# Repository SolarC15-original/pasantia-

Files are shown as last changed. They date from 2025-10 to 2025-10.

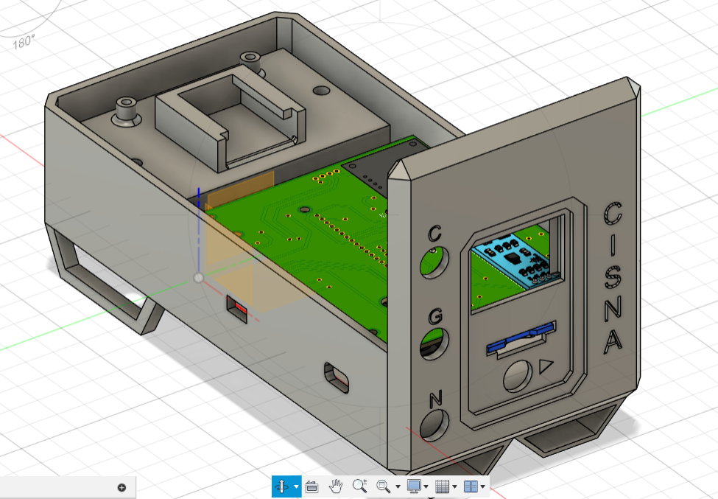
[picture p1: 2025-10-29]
modelo 3D caja ulima version/DiseñoFInal fotos/parte interna.png

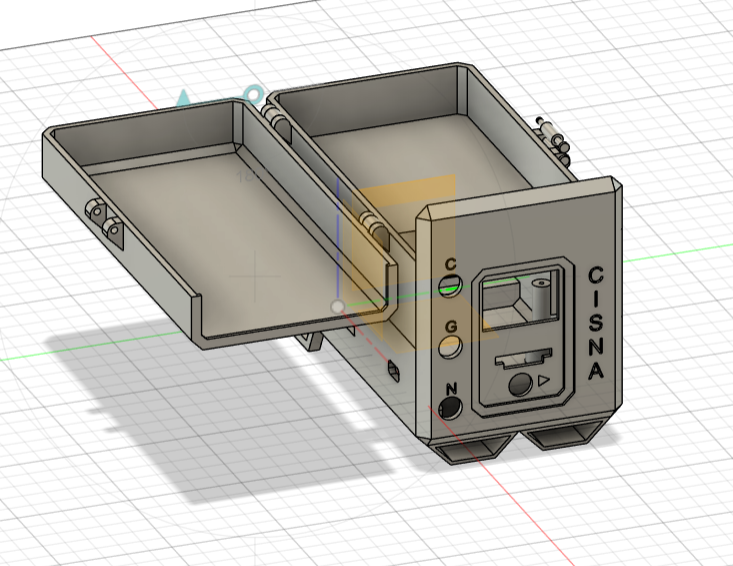
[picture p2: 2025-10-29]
modelo 3D caja ulima version/DiseñoFInal fotos/CajaFinal.png

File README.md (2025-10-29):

## 🎯 Propósito del repositorio

El propósito de este repositorio es **documentar y compartir todo el trabajo técnico realizado** durante el desarrollo del sensor NPK.  
Aquí se incluyen los archivos, códigos y recursos generados para facilitar la **continuidad del proyecto** y servir como referencia para futuros desarrollos o mejoras.

---

## 🧩 Contenido del repositorio

- `/3D_Model/` → Archivos del diseño 3D de la carcasa del sensor (formatos STL y editables).  
- `/Code/` → Código fuente del microcontrolador con las correcciones implementadas.  
- `/Docs/` → Documentación técnica, diagramas y reportes del proceso.  
- `/Tests/` → Registros de pruebas y observaciones de funcionamiento.  

---

## ⚙️ Funcionalidades principales

- Lectura de nutrientes NPK mediante sensor integrado.  
- Registro automático de la **fecha y hora** de toma de muestra.  
- Almacenamiento de datos en tarjeta SD.  
- Detección y notificación de **errores en la SD** o en los sensores.  
- Diseño modular y resistente para uso en campo.  

---

## 🧠 Tecnologías utilizadas

- **Arduino / C++** para programación del microcontrolador.  
- **Fusion 360 / FreeCAD** para diseño 3D.  
- **Sensores NPK y módulo SD** para adquisición y almacenamiento de datos.  
- **Impresoras 3D** para la fabricación de prototipos.  

---

## 📊 Resultados

- Carcasa 3D funcional, con mejoras en las dimensiones luego del primer prototipo.  
- Dispositivo completamente ensamblado y probado con muestras reales de suelo.  
- Código actualizado con manejo de fechas y detección de errores en la tarjeta SD.  

---

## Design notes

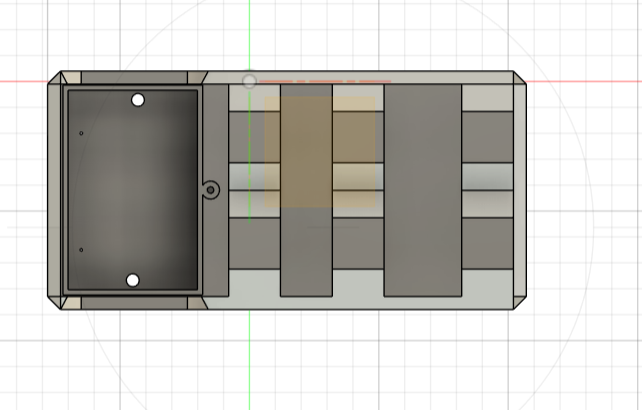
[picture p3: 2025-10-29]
modelo 3D caja ulima version/DiseñoFInal fotos/Parte inferior.png

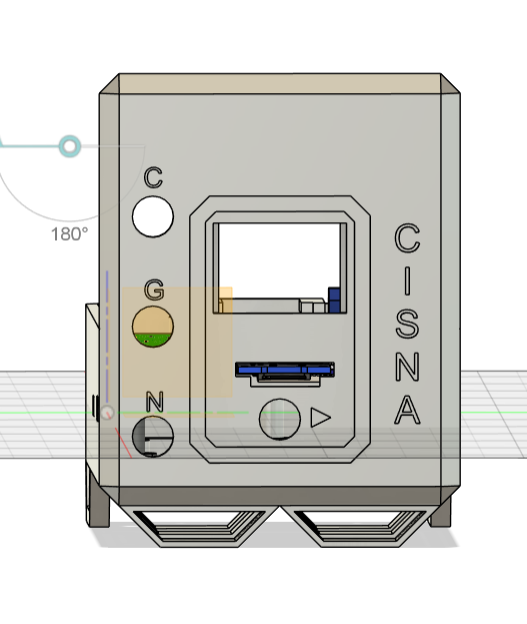
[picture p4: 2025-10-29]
modelo 3D caja ulima version/DiseñoFInal fotos/Tapa frontal.png

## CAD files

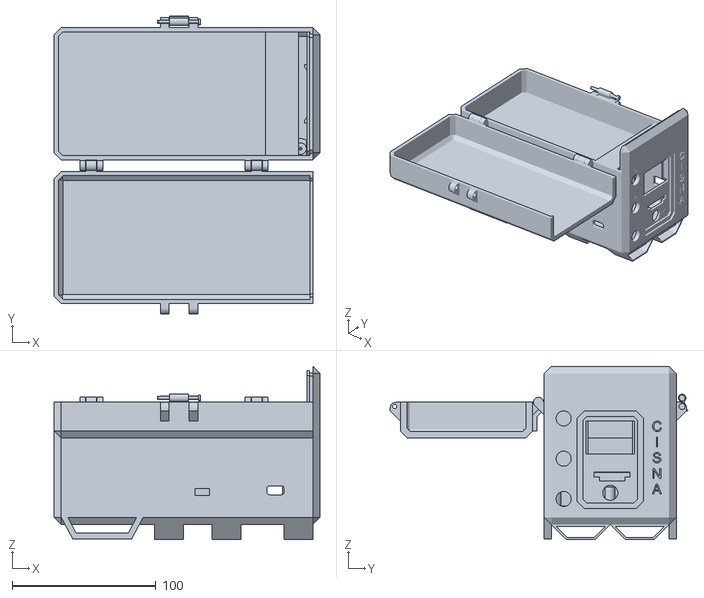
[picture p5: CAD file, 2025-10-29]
modelo 3D caja ulima version/cajanueva v11.stl
185.0 x 207.0 x 120.6

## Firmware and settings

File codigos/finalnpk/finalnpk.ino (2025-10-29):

#include <Wire.h>             // Librería para la comunicación I2C, usada por el OLED
#include <Adafruit_GFX.h>      // Biblioteca gráfica base para las pantallas Adafruit
#include <Adafruit_SH110X.h>   // Biblioteca específica para pantallas SH1106 (OLED)
#include <TinyGPS++.h>         // Biblioteca para interpretar datos del GPS
#include <SD.h>                // Biblioteca para manejo de tarjetas SD
#include <SPI.h>               // Biblioteca para la comunicación SPI (necesaria para la SD)

// ================== Configuración OLED ==================
#define SCREEN_WIDTH 128       // Ancho en píxeles de la pantalla OLED
#define SCREEN_HEIGHT 64       // Altura en píxeles de la pantalla OLED
#define OLED_RESET -1          // Pin de reset (no se utiliza un pin físico en este caso)
Adafruit_SH1106G display(SCREEN_WIDTH, SCREEN_HEIGHT, &Wire, OLED_RESET);

#define GPS_RX 4               // Pin para recibir datos del GPS
#define GPS_TX 2               // Pin para enviar datos al GPS (aunque realmente solo se recibe)
HardwareSerial GPSSerial(1);   // Se crea un puerto serial adicional para el GPS
TinyGPSPlus gps;               // Objeto para procesar la información del GPS

#define RO 33                  // Pin RX para el sensor de suelo vía RS485
#define DI 32                  // Pin TX para el sensor de suelo
#define RE 26                  // Pin para activar la recepción
#define DE 25                  // Pin para activar la transmisión

#define BUTTON_SAVE 14         // Pin asignado para el botón de guardar datos
#define BUTTON_NEW 27          // Pin asignado para el botón de crear un nuevo archivo
#define BUTTON_REFRESH 12      // Pin asignado para el botón de refrescar pantalla
#define SD_CS 5                // Pin Chip Select para la tarjeta SD
#define DEBOUNCE 200           // Tiempo de "debounce" para evitar múltiples activaciones

volatile uint8_t screenState = 0; // Estado de la pantalla: 0 = Sistema, 1 = Suelo
volatile bool flags[3] = {false, false, false}; // Flags para eventos: [refresh, save, newFile]
unsigned long lastInterrupt = 0;  // Controla el tiempo entre interrupciones
String currentFile = "";          // Guarda el nombre del archivo actual en la SD

struct SensorData {
  // Datos del GPS
  double lat = 0.0;
  double lng = 0.0;
  uint8_t hour = 0;
  uint8_t minute = 0;
  uint8_t second = 0;
  bool gpsValid = false;
  
  // Datos del sensor de suelo
  float temp = -1.0;
  float humidity = -1.0;
  unsigned int ec = 0;
  float ph = -1.0;
  unsigned int n = 0;
  unsigned int p = 0;
  unsigned int k = 0;
  unsigned int sal = 0;
  bool sensorValid = false;
};
class SoilSensor {
private:
  // Comando para solicitar datos del sensor (según protocolo RS485)
  const byte cmd[8] = {0x01, 0x03, 0x00, 0x00, 0x00, 0x08, 0x44, 0x0C};
  byte response[21]; // Buffer donde se almacena la respuesta del sensor
  
  // Función para combinar dos bytes y formar un entero de 16 bits
  uint16_t combinarBytes(uint8_t high, uint8_t low) {
    return (high << 8) | low;
  }

public:
  // Inicializa el sensor configurando el puerto serie y los pines de control
  void iniciar() {
    Serial2.begin(9600, SERIAL_8N1, RO, DI);
    pinMode(RE, OUTPUT);
    pinMode(DE, OUTPUT);
    digitalWrite(RE, LOW);
    digitalWrite(DE, LOW);
  }

  // Envía el comando al sensor y procesa la respuesta para actualizar los datos
  bool leer(SensorData &data) {
    // Activa la transmisión para enviar el comando
    digitalWrite(DE, HIGH);
    digitalWrite(RE, HIGH);
    delay(10);
    Serial2.write(cmd, 8);
    Serial2.flush();
    // Desactiva la transmisión para empezar a leer la respuesta
    digitalWrite(DE, LOW);
    digitalWrite(RE, LOW);

    uint8_t idx = 0;
    unsigned long inicio = millis();
    // Espera hasta 1 segundo o hasta recibir los 21 bytes esperados
    while((millis() - inicio < 1000) && (idx < 21)) {
      if(Serial2.available()) {
        response[idx++] = Serial2.read();
      }
    }
    
    // Verifica la integridad de la respuesta y asigna los valores a 'data'
    if(idx == 21 && response[0] == 0x01 && response[1] == 0x03) {
      data.temp = combinarBytes(response[3], response[4]) / 10.0;
      data.humidity = combinarBytes(response[5], response[6]) / 10.0;
      data.ec = combinarBytes(response[7], response[8]);
      data.ph = combinarBytes(response[9], response[10]) / 100.0;
      data.n = combinarBytes(response[11], response[12]);
      data.p = combinarBytes(response[13], response[14]);
      data.k = combinarBytes(response[15], response[16]);
      data.sal = combinarBytes(response[17], response[18]);
      data.sensorValid = true; // Los datos recibidos son válidos
      return true;
    }
    data.sensorValid = false; // Si la respuesta falla, se marca el sensor como inválido
    return false;
  }
};

SoilSensor sensorSuelo;  // Instancia para manejar el sensor de suelo
SensorData datos;        // Variable global para almacenar los datos recopilados


void IRAM_ATTR handleRefresh() {
  if(millis() - lastInterrupt > DEBOUNCE) {
    flags[0] = true;
    lastInterrupt = millis();
  }
}

void IRAM_ATTR handleSave() {
  if(millis() - lastInterrupt > DEBOUNCE) {
    flags[1] = true;
    lastInterrupt = millis();
  }
}

void IRAM_ATTR handleNewFile() {
  if(millis() - lastInterrupt > DEBOUNCE) {
    flags[2] = true;
    lastInterrupt = millis();
  }
}

// ================== Función setup() ==================
void setup() {
  digitalWrite(22, LOW);  // Inicia el reinicio del sistema
  delay(1200); 
  Serial.begin(115200);   // Inicia la comunicación serial para debug

  // Inicializa la pantalla OLED y muestra la pantalla de inicio
  display.begin(0x3C, true);
  display.setTextColor(SH110X_WHITE);
  mostrarSplash();
  
  // Inicializa el GPS y el sensor de suelo
  GPSSerial.begin(9600, SERIAL_8N1, GPS_RX, GPS_TX);
  sensorSuelo.iniciar();
  
  // Configura los botones con resistencia interna pull-up
  pinMode(BUTTON_REFRESH, INPUT_PULLUP);
  pinMode(BUTTON_SAVE, INPUT_PULLUP);
  pinMode(BUTTON_NEW, INPUT_PULLUP);
  // Asocia cada botón a su función de interrupción
  attachInterrupt(BUTTON_REFRESH, handleRefresh, FALLING);
  attachInterrupt(BUTTON_SAVE, handleSave, FALLING);
  attachInterrupt(BUTTON_NEW, handleNewFile, FALLING);
  
  // Inicializa la tarjeta SD y crea un archivo nuevo para almacenar datos
  if(!SD.begin(SD_CS)) {
    mostrarError("Error en SD!");
    while(true);
  }
  crearNuevoArchivo();
}

void loop() {
  actualizarGPS();         // Procesa los datos entrantes del GPS
  actualizarSensorSuelo(); // Lee los datos del sensor de suelo
  manejarEventos();        // Maneja eventos generados por los botones
  actualizarPantalla();    // Refresca la pantalla OLED
  delay(100);
}


// Lee datos del puerto serial del GPS y actualiza la estructura 'datos'
void actualizarGPS() {
  while(GPSSerial.available()) {
    if(gps.encode(GPSSerial.read())) {
      // Verifica que tanto la ubicación como la hora sean válidas
      datos.gpsValid = gps.location.isValid() && gps.time.isValid();
      if(datos.gpsValid) {
        datos.lat = gps.location.lat();
        datos.lng = gps.location.lng();
        datos.hour = gps.time.hour()-5; // Ajuste de zona horaria a Colombia
        datos.minute = gps.time.minute();
        datos.second = gps.time.second();
      }
    }
  }
}

// Realiza una lectura del sensor cada 2 segundos
void actualizarSensorSuelo() {
  static unsigned long ultimaLectura = 0;
  if(millis() - ultimaLectura > 2000) {
    sensorSuelo.leer(datos);
    ultimaLectura = millis();
  }
}

//  Función para Manejar Eventos  
void manejarEventos() {
  if(flags[0]) { // Si se presionó el botón de refrescar
    screenState = (screenState + 1) % 2;
    flags[0] = false;
  }
  
  if(flags[1]) { // Si se presionó el botón de guardar datos
    guardarEnSD();
    flags[1] = false;
    mostrarMensajeTemporal("Dato Guardado");
  }
  
  if(flags[2]) { // Si se presionó el botón para nuevo archivo
    crearNuevoArchivo();
    flags[2] = false;
    mostrarMensajeTemporal("Nuevo Archivo");
  }
}

// Función para Crear un Nuevo Archivo en la SD 
void crearNuevoArchivo() {
  uint8_t numArchivo = 1;
  do {
    currentFile = "/DAT" + String(numArchivo < 10 ? "0" : "") + String(numArchivo) + ".CSV";
    numArchivo++;
  } while(SD.exists(currentFile));
  
  // Abre el archivo y designa los nombres de cada columna
  File archivo = SD.open(currentFile, FILE_WRITE);
  if(archivo) {
    archivo.println("Latitud,Longitud,Hora,Min,Seg,Temp,Humedad,CE,pH,N,P,K,Sal");
    archivo.close();
  }
}

// Función para Guardar Datos en la SD 
void guardarEnSD() {
  File archivo = SD.open(currentFile, FILE_APPEND);
  if(archivo) {
    archivo.printf("%.6f,%.6f,%02d,%02d,%02d,%.1f,%.1f,%d,%.2f,%d,%d,%d,%d\n",
                  datos.lat,
                  datos.lng,
                  datos.hour,
                  datos.minute,
                  datos.second,
                  datos.temp,
                  datos.humidity,
                  datos.ec,
                  datos.ph,
                  datos.n,
                  datos.p,
                  datos.k,
                  datos.sal);
    archivo.close();
  }
}

// Función para Actualizar la Pantalla 
void actualizarPantalla() {
  display.clearDisplay();
  display.setCursor(0, 0);
  
  if(screenState == 0) { // Muestra la información del sistema
    display.println("== SISTEMA ==");
    
    if(datos.gpsValid) {
      display.printf("Lat:%.6f\n", datos.lat);
      display.printf("Lon:%.6f\n", datos.lng);
    } else {
      display.println("GPS: Sin senal");
    }
    
    display.printf("Hora: %02d:%02d:%02d\n", 
                  datos.hour, 
                  datos.minute, 
                  datos.second);
    
    // Muestra el nombre del archivo actual d
    String nombreCorto = currentFile.substring(1);
    if(nombreCorto.length() > 16) {
      display.println(nombreCorto.substring(0, 16));
      display.println(nombreCorto.substring(16));
    } else {
      display.println(nombreCorto);
    }
  }
  else { // Muestra los datos del sensor de suelo
    display.println("== DATOS SUELO ==");
    if(datos.sensorValid) {
      display.printf("T:%.1fC H:%.1f%%\n", datos.temp, datos.humidity);
      display.printf("CE:%d pH:%.2f\n", datos.ec, datos.ph);
      display.printf("N:%d P:%d K:%d\n", datos.n, datos.p, datos.k);
      display.printf("Sal:%d", datos.sal);
    } else {
      display.println("Error en sensor!");
    }
  }
  display.display();  // Envía la información actualizada a la pantalla
}

//  Función para Mostrar la Pantalla de Inicio 
void mostrarSplash() {
  display.clearDisplay();
  display.setTextSize(2);
  display.setCursor(15, 20);
  display.print("AGROTECH");
  display.setTextSize(1);
  display.setCursor(30, 45);
  display.print("INICIANDO...");
  display.display();
  delay(2000);
  display.setTextSize(1);
  display.clearDisplay();
}

// Función para Mostrar un Mensaje 
void mostrarMensajeTemporal(const char* msg) {
  display.clearDisplay();
  display.setCursor(10, 28);
  display.print(msg);
  display.display();
  delay(800);
}

//  Función para Mostrar un Mensaje de Error
void mostrarError(const char* msg) {
  display.clearDisplay();
  display.setTextColor(SH110X_WHITE);
  display.setCursor(0, 0);
  display.print("ERROR:");
  display.setCursor(0, 20);
  display.print(msg);
  display.display();
}
